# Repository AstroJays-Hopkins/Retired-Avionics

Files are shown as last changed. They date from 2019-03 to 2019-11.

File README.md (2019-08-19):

# Onboard Avionics and Ground Support Electronics

Avionics computer programs (excluding ground station GUI) and circuit schematics.  Program design documents and other non-program files may be found on team internet storage.

## Some directories of interest

* ```propulsion/```  --- Programs that control rocket propulsion systems
  * ```propulsion/darts```  --- Rocket's Data Acquisition, Recording, and Telemetry System
  * ```propulsion/ignition```  --- Programs to monitor and actuate the rocket's ignition hardware
* ```recovery/```  --- Programs that make sure the rocket can fly again
* ```ground-tests/```  --- Programs to help determine if the rocket can (should) even fly in the first place
* ```libraries/```  --- Custom libraries written in-house (one-of-a-kind --- you won't find them elsewhere!) and modified sensor libraries.

For detailed information about a particular subsystem, please consult the READMEs in that subsystem's directory.

_Made in Baltimore with love, tears, caffine, swearing, all-nighters, hair-pulling, stolen code, grimacing, git-cursing, and shocking realizations about engineering._

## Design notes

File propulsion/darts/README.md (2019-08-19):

# Data Acquisition Recording and Transmission System (DARTS)

> <del>_Bata Bacquisition Becording band Bransmission Bystem (BBBbBB)_</del>

Reads data from various sensors
(load cells, pressure transducers, thermocouples),
records the data to disk,
and transmits it to a ground station via WiFi.

## Files

* ```main.py```  --- Main program; calls programs defined in other files
  to collect, record, and transmit data.
  Run this in Python to use the system
  (see section _Starting up the DARTS_).
* ```pressure_transducer.py```  --- Methods to read pressure transducers
  via ADC over I2C
* ```RocketThermocouple.py```  --- Methods to read thermocouples via SPI
* ```load_cell.py```  --- Methods to read load cell via serial.
  Currently only works for single load cell.
  *FIXME:* Implement support for multiple load cells.
* ```HX711_Load_Cell/```  --- Programs that run on actual load cell board (not the Pi).  Consult A. Cornelio for details.
    * ```HX711_Load_Cell/README```  --- A. Cornelio's notes on the load cell program
* ```SendToFlask.py```  --- HTTP client that transmits data
  to Flask server for display on GUI
  (this is how our data gets beamed off the rocket).
  Consult H. Mason for details.
* Files that aren't used or don't work that well:
    * ```3LCtoPi.ino```  --- Serial meta-serializer program for Arduino.
    It's supposed to read three serial inputs (from load cells)
    and collate the data into one long stream
    that it outputs on the fourth serial port to the Pi
    (or other master computer).  Doesn't work, but we're not sure why.
    * ```Server.py``` and ```Client.py```  --- Prototype programs
    to transmit data off of rocket using TCP sockets.
    Kept for historical interest --- the programs have
    some useful instructions on how to determine the IP address of the Pi
    by using a separate computer to log into the system's router.

### Things to be aware of about the code

* GPIO pin numberings in the code use the BCM chip numbering scheme.
  You can find the BCM chip number associated with each header pin
  [here](https://pinout.xyz/).

## Starting up the DARTS

1. Connect the pieces.  See section _Connections_ for details on how to
   connect the sensors, router, and Pi together.
1. Power everything up.
1. Determine the IP address of the Pi.
   Using a separate computer, connect to the system's TP-Link router Wifi signal.
   Then visit tplinklogin.net or 192.168.0.1 in a web browser,
   click on DHCP -> Address Reservation,
   and look for the IP address of the Pi.
   If the Pi's IP address is not immediately obvious,
   compare the MAC addresses listed under DHCP -> Address Reservation
   to that for "blueberrypi" in DHCP -> DHCP Clients List ,
   or eliminate known IP addresses for other computers.
1. Once you have found the IP address of the Pi,
   log into it remotely using SSH:
       ```
          ssh pi@<ip address of Pi>
       ```
   Enter the password to the Pi; you should then see a shell prompt.
1. In the Pi shell over SSH, switch to DARTS code directory:
       ```
          cd rocket/Avionics/propulsion/darts
       ```
1. Start the Python system:
       ```
          python -i main.py
       ```
   System should start reading sensors and transmitting it
   to the Flask server that the GUI obtains data from.
   Data should also be written to file ```DATA1.csv```.
1. On a computer that has the GUI installed,
   start the GUI and navigate to the GUI webpage.
   You should be able to see the GUI displaying data from the sensors.
   For good measure, manipulate the sensors
   and watch for pertubations in their readouts on the GUI.
   For information on how to install and start the GUI,
   please see the GUI's [Git repository](https://github.com/AstroJays-Hopkins/Ground-Station-Wet-Dress).

### SSH

If you're on a Unix-like system,
please refer to your operating system's instructions
for how to install ```ssh```.
Users of Microsoft Windows NT-derived operating systems may download
[PuTTY](https://www.chiark.greenend.org.uk/~sgtatham/putty/).

Note on PuTTY: Ignore the site ```putty DOT org```.
It is not affiliated with the developers of PuTTY
and appears to advertise for competing SSH software.
The correct link to the official PuTTY site is reproduced again here:
[https://www.chiark.greenend.org.uk/~sgtatham/putty/](https://www.chiark.greenend.org.uk/~sgtatham/putty/)

Anyone who is the recipient of unsolicited "sssshhh!" jokes
when discussing SSH is hereby authorized to slap the party
delivering such jokes.
It is further recognised that such "sssshhh!" jokes are stale.

## Connections

__FIXME:__ Document how to put the system together.

## Things to fix, verify, and improve

Until further notice, issues should only be opened on GitHub for problems in code.

- [ ] __VERIFY:__ Is one of the Pis bricked?

- [ ] __VERIFY:__ Does DARTS still calculate critical oxidizer tank conditions and automatically shut off the rocket motor and vent the tank if the tank goes critical?

- [ ] __FIXME:__ Clean up merge conflicts in ```main.py```
- [ ] __FIXME:__ Implement way to read from multiple load cells
- [ ] __FIXME:__ Diagnose thermocouples
- [ ] __FIXME:__ Build better housings and connections between components

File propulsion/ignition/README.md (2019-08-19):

# Ignition system programs and schematics

Name says it all.

Schematic and PCB design are done using [KiCAD](http://kicad-pcb.org/).

## Files

* ```schematic/```  --- Schematics for ignition system
* ```comparator-circuits/```  --- Schematics and PCB design files for the
  continuity tester circuits used in the ignition system

### Things to know about the schematics

* Suggested changes to the schematics are presented in the ```future``` branch.

## Explanation of system

> _Bug avnoks for further details._

The ignition system consists of three parts: the part to light the ematch,
the part to open the oxidizer ball valve,
and the radio device (the "football") that controls the first two parts.
The system is designed around the following principles:

* Safety is implemented in hardware.
  The system's safety should arise from its physical properties,
  not from software checks.
  > Use physical switches as opposed to if statements.
  Never should software be the only thing preventing an unauthorised launch.
* The system should fail safe.
  Should a component of the system stop working,
  it should do so in a way that does not compromise the rest of the system
  and does not cause an unauthorised launch.
* Ultimate control of the system and the launch of the rocket
  should reside in one person.
  This is accomplished by giving the one key
  that arms all switches throughout the system and launches the rocket
  to only one person who is also the last person to leave the pad.
* The system should communicate unambiguously.

### Ematch

The ematch part of the system consists of a battery,
an ematch,
and circuitry to prevent the battery from lighting the ematch
when it's not supposed to.
The battery is housed alongside a relay, radio, and other circuitry
in a relay box located 50 imperial feet away from the rocket
(the radio recieves the command to light the ematch
and activates the relay to connect the battery
to the wires going to the ematch).
The ematch is buried in a block of propellant
suspended in the fuel grain of the rocket;
it is connected to the relay box
through a long wire and some more safety circuitry.
The safety circuitry consists primarily of voltage warning signals,
two switches,
and continuity testers

#### Voltage warning signals

A buzzer and a white LED
in the relay box
and another buzzer and white LED in the rocket
warn launch personnel when there is voltage across the wire
that supplies the ematch with electricity.
Should launch personnel observe these buzzers and LEDs activate,
they should immediately retreat from the pad
and await further instructions.

**FIXME:** Identify frequency of buzzer.

#### Switches

Two key switches are built into the circuit:
a shunt switch,
which is on the relay box,
and a safety switch,
which is on the rocket.
The shunt switch shorts out the wires
that supply electricity to the ematch.
It should be closed whenever personnel are closer to the rocket
than the relay box is (within 50 feet of the rocket).
The safety switch interrupts the wires supplying electricity to the ematch.
It should remain open unless personnel
are about to retreat to a safe area for launch.
Personnel should never close the safety switch
if they observe the voltage warning signals described above.

#### Continuity testers

The continuity testers detect when the switches,
relay,
and ematch in the system have continuity.
For the relay and switches,
the testers sound a buzzer and light an LED
when the component monitored is in an unsafe state
(unsafe means that fewer things need to happen
in order for the rocket to launch).

The continuity testers are built from comparators.
The theory behind them can be found at David Johnson-Davies's
[post on a similar tester.](http://www.technoblogy.com/show?1YON)
In short,
one of the comparator's inputs is tied to a voltage reference
created using a voltage divider.
The other input is connected to one side of the device
whose continuity is to be tested;
the ground of the comparator
is connected to the other side.
When there is continuity,
the second input of the comparator is shorted to ground,
which is less than the reference voltage.
This activates the comparator's output,
which turns on various buzzers and LEDs.

The LM393 comparators used in the system
is an open collector device ---
its output conducts to ground when it is active.

### Motorised Ball Valve (MBV)

Radio module receives launch signal from football.
Waits a bit for relay box to light ematch
and start combustion of fuel grain.
Then checks to see if there still is continuity across the ematch.
If there isn't (match has burnt through),
opens ball valve.

**FIXME:** Where's all the code?

### Football

Radio transceiver that transmits launch command to MBV and relay box.
Should in future receive and display continuity tester data
back from relay box and rocket
(state of relay, switches, and ematch).

## Things to fix

- [ ] **TODO:** Teach everyone on the team what the different signals
                (voltage, continuity)
                look and sound like.
- [ ] **TODO:** Post labels on system describing what to do if a particular signal is observed.

- [ ] __TODO:__ Check design of system in ```future``` branch,
                then order new PCBs.
- [ ] __TODO:__ Assemble modified system

- [ ] __TODO:__ Label physical components with designators from schematics
- [ ] __TODO:__ Build physical housing for system

- [ ] __VERIFY:__ Does MBV controller know when ematch has burnt through?

- [ ] __FIXME:__ Optoisolate inputs between different parts of system
- [ ] __FIXME:__

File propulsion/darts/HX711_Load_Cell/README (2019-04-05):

Andrew's Changes:

Load cell is pretty straightforward now. press a to find the 0 point, b (with a weight on the load cell and correct weight in
kg in the file) to calibrate the load cell, and c to read the weights. Uses some form of gradient descent to find correct
calibration. Don't change unless you know what you're doing. Chances are it's a mechanical failure, not a load cell failure!!!

HX711
=====

An Arduino library to interface the Avia Semiconductor HX711 24-Bit Analog-to-Digital Converter (ADC) for Weight Scales.

This is my humble attempt at creating an Arduino library for this ADC:
http://www.dfrobot.com/image/data/SEN0160/hx711_english.pdf

Other libraries exist, including this very good one, which I first used and which is the starting point for my library:
https://github.com/aguegu/ardulibs/tree/master/hx711

# Advantages of this library
Although other libraries exist, I needed a slightly different approach, so here's how my library is different than others:

1. It provides a tare() function, which "resets" the scale to 0. Many other implementations calculate the tare weight when the ADC is initialized only. I needed a way to be able to set the tare weight at any time. Use case: place an empty container on the scale, call tare() to reset the readings to 0, fill the container and get the weight of the content.

2. It provides a power_down() function, to put the ADC into a low power mode. According to the datasheet, "When PD_SCK pin changes from low to high and stays at high for longer than 60μs, HX711 enters power down mode". Use case: battery powered scales. Accordingly, there is a power_up() function to get the chip out of the low power mode.

3. It has a set_gain(byte gain) function that allows you to set the gain factor and select the channel. According to the datasheet, "Channel A can be programmed with a gain of 128 or 64, corresponding to a full-scale differential input voltage of ±20mV or ±40mV respectively, when a 5V supply is connected to AVDD analog power supply pin. Channel B has a fixed gain of 32.". The same function is used to select the channel A or channel B, by passing 128 or 64 for channel A, or 32 for channel B as the parameter. The default value is 128, which means "channel A with a gain factor of 128", so one can simply call set_gain(). Also, the function is called from the constructor.

4. The constructor has an extra parameter "gain" that allows you to set the gain factor and channel. The constructor calls the "set_gain" function mentioned above.

5. The "get_value" and "get_units" functions can receive an extra parameter "times", and they will return the average of multiple readings instead of a single reading.

# How to Calibrate Your Scale

1. Call set_scale() with no parameter.
2. Call tare() with no parameter.
3. Place a known weight on the scale and call get_units(10).
4. Divide the result in step 3 to your known weight. You should get about the parameter you need to pass to set_scale.
5. Adjust the parameter in step 4 until you get an accurate reading.

# How to use
See the example in examples/HX711SerialBegin. Please don't use examples/HX711Serial anymore. It is deprecated because the pin definition within the constructor
is not timing safe. (#29)

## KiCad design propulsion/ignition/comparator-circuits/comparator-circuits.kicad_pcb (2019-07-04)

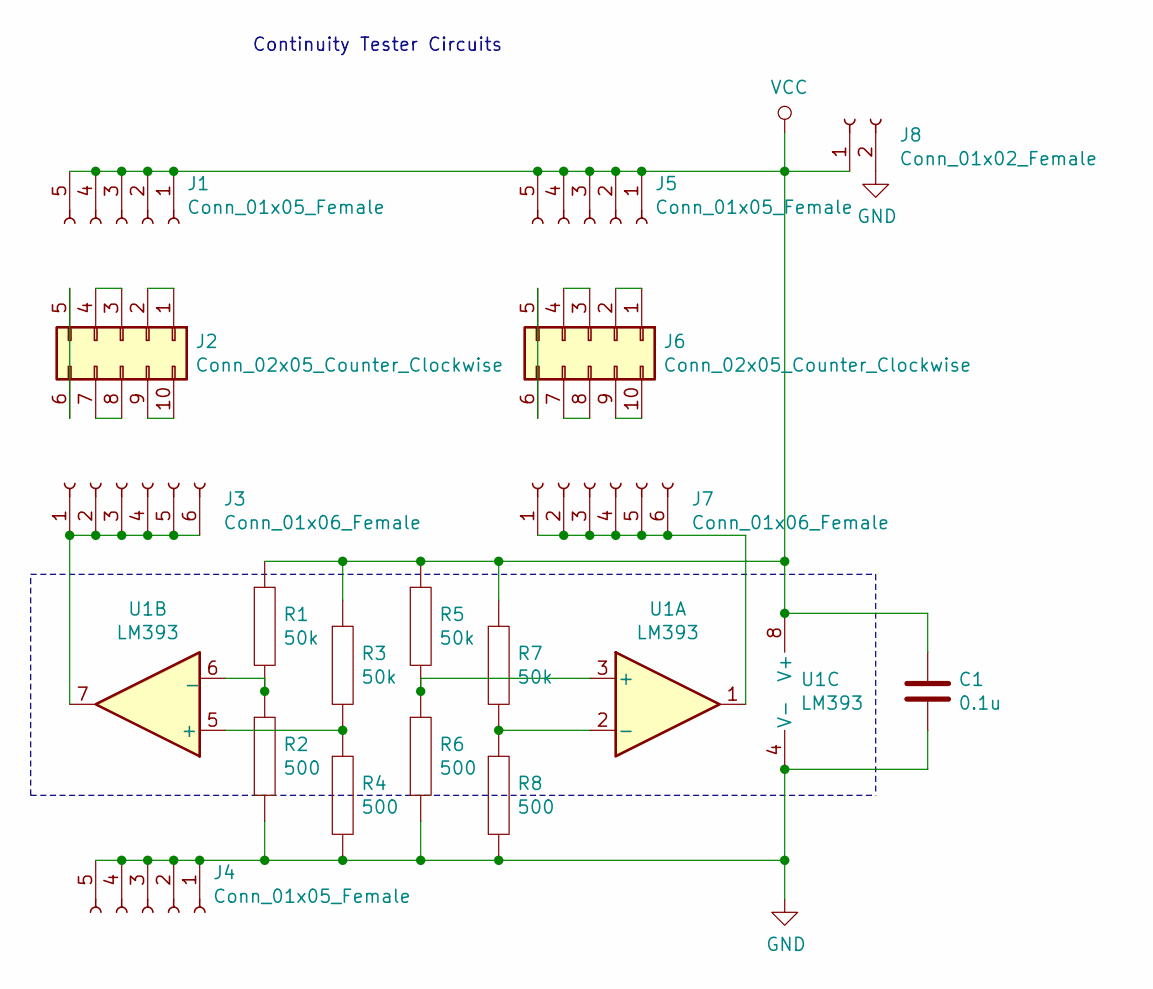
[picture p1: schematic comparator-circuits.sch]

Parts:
C1: 0.1u; C_Disc_D3.0mm_W2.0mm_P2.50mm
J1, J4, J5: Conn_01x05_Female; PinHeader_1x05_P2.54mm_Vertical
J2, J6: Conn_02x05_Counter_Clockwise; PinHeader_2x05_P2.54mm_Vertical
J3, J7: Conn_01x06_Female; PinHeader_1x06_P2.54mm_Vertical
J8: Conn_01x02_Female; PinHeader_1x02_P2.54mm_Vertical
R1, R3, R5, R7: 50k; R_Axial_DIN0207_L6.3mm_D2.5mm_P7.62mm_Horizontal
R2, R4, R6, R8: 500; R_Axial_DIN0207_L6.3mm_D2.5mm_P7.62mm_Horizontal
U1: LM393; DIP-8_W7.62mm

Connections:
GND: C1.2, J4.1, J4.2, J4.3, J4.4, J4.5, J8.2, R2.2, R4.2, R6.2, R8.2, U1.4 (V-)
unnamed: J2.1, J2.2
unnamed: J2.3, J2.4
unnamed: J2.5, J2.6
unnamed: J2.7, J2.8
unnamed: J2.9, J2.10
unnamed: J3.1, J3.2, J3.3, J3.4, J3.5, J3.6, U1.7
unnamed: J6.1, J6.2
unnamed: J6.3, J6.4
unnamed: J6.5, J6.6
unnamed: J6.7, J6.8
unnamed: J6.9, J6.10
unnamed: J7.1, J7.2, J7.3, J7.4, J7.5, J7.6, U1.1
unnamed: R1.2, R2.1, U1.6 (_)
unnamed: R3.2, R4.1, U1.5 (+)
unnamed: R5.2, R6.1, U1.3 (+)
unnamed: R7.2, R8.1, U1.2 (-)
VCC: C1.1, J1.1, J1.2, J1.3, J1.4, J1.5, J5.1, J5.2, J5.3, J5.4, J5.5, J8.1, R1.1, R3.1, R5.1, R7.1, U1.8 (V+)

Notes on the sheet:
Continuity Tester Circuits

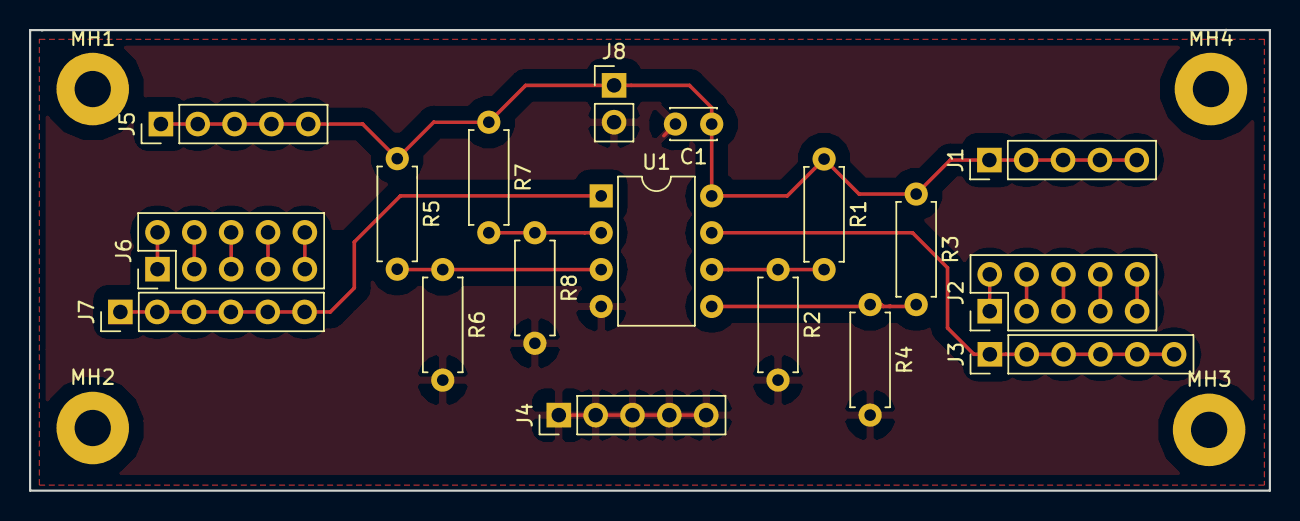
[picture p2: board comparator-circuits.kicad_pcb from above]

Board: 2 copper layers, 85.5 x 31.8 mm, 22 parts (0 on the bottom side), 18 nets.

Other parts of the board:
MH1, MH2, MH3, MH4: MountingHole_2.5mm_Pad

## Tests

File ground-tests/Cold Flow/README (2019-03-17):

Peripheral_Mega.ino 
----------------------------------------------------------
>collects data from load cells using UART serial communication 
>calculates venting time based off duration of continutity of a button press circuit
>determines open/closed condition of quick disconnect solenoid
>writes data to ground station via I2C communication

Sensing_Mega.ino
----------------------------------------------------------
>collects pressure data via analog pressure transducers
>collects temperature data using SPI thermocouples
>determines critical condition of the oxidizer
>sends back information via I2C communication

Ground_Station_Reader.ino
----------------------------------------------------------
>collects information sent from peripheral and sensing devices
>formats data for use in Flask.app GUI
>exports data for use in GUI via UART serial communication
>logs data on SD card

Wet_Dress.ino
----------------------------------------------------------
>serves the same purpose as Peripheral_Mega.ino and Sensing_Mega.ino but on one board
>transmits data via USB serial to GUI

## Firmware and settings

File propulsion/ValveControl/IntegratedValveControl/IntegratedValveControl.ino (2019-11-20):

/* 
 *  Control code for ball valve and solenoid valves.  
 *  Reads Hall effect detector
 *  built into the AndyMark RS-775 motor to measure rotation.
 *  
 *  The ball valve section of the code is:
 *  Code adapted and pilfered from Jeffrey La Favre:
 *    http://www.lafavre.us/robotics/encoder_code.pdf
 *  An explanation of Hall effect encoders, also 
 *  by La Favre: 
 *    http://www.lafavre.us/robotics/Hall_Encoders.pdf
 *  Do take the technical explanation located above with a grain of salt.
 *  
 *  BEFORE EDITING THIS PROGRAM, please read the
 *  "Notes and Warnings" on interrupts here: 
 *    https://www.arduino.cc/reference/en/language/functions/external-interrupts/attachinterrupt/
 *
 */

//Commands will be sent via 915MHz radio communication
#include <SPI.h>
#include <LoRa.h>
#include <Wire.h>
#include <TimerOne.h>

#include "motor.h"
#include "radio.h"

/* *** MOTOR RELAY PINS for BV VALVES*** */
// Signal pin to relay that is currently powering motor.  If no relay is
// currently on (running a motor), this variable will be 0 .
int Active_Relay_Pin = 0;
int Low_Relay_Pin = 0;
const int PIN_EMATCH_CONT = 52;


// States for the above pins
bool Valve_state = false;   // HIGH -> open; LOW -> closed 


/* *** RELAY PINS for Solenoid Valves */
const int fuelRelay = 6;
const int ventRelay = 23;
//States for the above pins
bool Fuel_state = false;
bool Vent_state = false;

/* *** IGNITION PARAMETER *** */
volatile uint8_t igniter_x_cnt = 0;
volatile uint8_t stop_x_cnt = 0;
volatile bool ignited = false;
bool shut_bv_after_ignition = false;
const int burn_duration = 650; // The duration for the ignition burn, in 10ms.
long burn_time = 0;

bool ematch_continuity = false; // Check if ematch is burnt through.

DCMotorController MV_R1(rkt::MV_R1_CLICKS);

void MV_R1_pulse() {
  MV_R1.handlePulseEvent();
}

void MV_R1_limit() {
  MV_R1.handleLimitSwitch();
}


void switch_solenoid_valve(int valve_pin, int state){
  digitalWrite(valve_pin, state);
}

void stopRun() {
  // The ignition function will run twice before we actually want it to ignite
  // Once when the interrupt is attached, and once when the timer is started
  if (stop_x_cnt > 1) {
    MV_R1.actuate(1);
    Timer1.stop();
    Timer1.detachInterrupt();
    stop_x_cnt = 1;
  } else {
    ++igniter_x_cnt;
  }
}

void ignition() {
  // The ignition function will run twice before we actually want it to ignite
  // Once when the interrupt is attached, and once when the timer is started
  if (igniter_x_cnt > 1) {
    MV_R1.actuate(2);
    Timer1.stop();
    Timer1.detachInterrupt();
    Timer1.setPeriod(7000000);
    Timer1.stop();
    Timer1.attachInterrupt(stopRun);
    Timer1.start();
    igniter_x_cnt = 1;
  } else {
    ++igniter_x_cnt;
  }
}

void emergency() {
    // fill with emergency code
}

//Every time data is requested, send data back.
void writeI2C() {
  uint8_t ecstate = (int) Vent_state; //vent
  ecstate += (int) MV_R1.valve_moving << 1; //ball valve Moving
  ecstate += (int) MV_R1.state << 2; //ball valve
  ecstate += (int) ematch_continuity << 3; //e-match
  ecstate += (int) Fuel_state << 4; //fuel
  Wire.write(ecstate);
}

void readI2C() {
  byte command = Wire.read();
  // read off vent command
  commands[2] = (command & (0b11 << 1)) >> 1;
  // emergency shutdown command
  if(command & 0b1) emergency();
}

RfTr rf_tr(0b0001);

void setup() {
  /* Initialize radio communication protocol */
  LoRa.begin(915E6);
  LoRa.setTxPower(2);
  Serial.begin(115200);
  Wire.begin(0x10);
  Wire.onReceive(readI2C);
  Wire.onRequest(writeI2C);

  /* Initialize relay signal pins */
  pinMode(rkt::PIN_MOTOR_FWD, OUTPUT);
  pinMode(rkt::PIN_MOTOR_REV, OUTPUT);
  
  //set relay pins to output voltage
  pinMode(ventRelay,OUTPUT);
  pinMode(fuelRelay, OUTPUT);
  pinMode(rkt::PIN_INTR_ENCODER, INPUT);
  pinMode(rkt::PIN_INTR_LIMIT, INPUT_PULLUP);

  attachInterrupt(digitalPinToInterrupt(rkt::PIN_INTR_ENCODER), MV_R1_pulse, RISING);
  attachInterrupt(digitalPinToInterrupt(rkt::PIN_INTR_LIMIT), MV_R1_limit, FALLING);

  //set default relay states to LOW (default)
  digitalWrite(ventRelay, HIGH);
  digitalWrite(fuelRelay, LOW);
  digitalWrite(rkt::PIN_MOTOR_FWD, LOW);
  digitalWrite(rkt::PIN_MOTOR_REV, LOW);

//  //setup timer2 interrupt for ignition procedure. 1kHz -> 64 prescalar + 249 compare interrupt
//  // The control of the rocket will be disabled during ignition if delay() is used, which is blocking.
//  TCCR2A = 0;
//  TCCR2B = 0;
//  TCNT2 = 0;
//  OCR2A = 249;
//  
//  TCCR2A |= (1 << WGM21);
//  TCCR2B |= (1 << CS22);
//  TIMSK2 |= (1 << OCIE2A);
  Serial.print("Set Pulses: ");
  Serial.println(MV_R1.set_pulses);
  sei();
  Timer1.initialize(650000);
  Timer1.attachInterrupt(ignition);
  Timer1.stop();
}

//void ignition_duration_check(){
//  if (ignited && (ematch_continuity = true) ){
//    burn_time += 1;
//    if (burn_time >= burn_duration){
//      RECVD_IG_CMD = 0;
//      MV_R1.actuate(2);
//      shut_bv_after_ignition = true;
//    }
//  }
//}

void checkEMatchCont() {
  ematch_continuity = digitalRead(PIN_EMATCH_CONT);
}

int curPulse = 0;

void loop() {
//  if(curPulse != MV_R1.current_pulses) {
//    curPulse = MV_R1.current_pulses;
//    Serial.print("PULSE CHANGED: ");
//    Serial.println(curPulse);
//  }
  // Put code in to activate relays upon request.
  rf_tr.check_receive_packet();
  checkEMatchCont();
    
  uint8_t BV_Command = commands[0]; //check ball valve desired state
  switch (BV_Command) { //set desired ball valve state
    case 255: // TODO check char types
      Serial.println("IG CASE");
      Serial.println("RECVD IGNITION CMD...");
      Timer1.restart();
      commands[0] = 2;
      break;
  case 2:
    Serial.println("Valve Open");
    MV_R1.actuate(2);
    commands[2] = 0;
    break;
  case 1:
    Serial.println("valve close");
    MV_R1.actuate(1);
    commands[2] = 0;
    break;
  case 0:
    // Serial.println("HOLDING");
    break;
  }

  int8_t Fuel_Command = commands[2]; //Check fuel valve desired state
  switch (Fuel_Command) { //set desired fuel valve state
    case 2:
      Fuel_state = true;
      Serial.println("FUEL OPEN");
      break;
    case 1:
      Fuel_state = false;
      Serial.println("FUEL CLOSE");
      break;
  }
  
  int8_t Vent_Command = commands[1]; //Check vent valve desired state
  switch (Vent_Command) { //set desired vent valve state
    case 2:
      Vent_state = true;
      switch_solenoid_valve(ventRelay, 1); //Vent valve is normally open.
      commands[0] = 2;
      break;
    case 1:
      Vent_state = false;
      switch_solenoid_valve(ventRelay, 0);
      commands[0] = 1;
      break;
  }
  commands[0] = 0;
  commands[1] = 0;
  commands[2] = 0;
  //Serial.println("------------------------------");
}

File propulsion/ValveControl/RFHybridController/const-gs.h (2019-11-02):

#ifndef __CONST_GS_H__
#define __CONST_GS_H__

namespace rkt {
    const uint8_t PIN_IN_SV_R1_ENA   = 49;
    const uint8_t PIN_IN_MV_G1_CLOSE = 48;
    const uint8_t PIN_IN_IGNITION    = 47;
    const uint8_t PIN_IN_MV_G1_OPEN  = 46;
    const uint8_t PIN_IN_MV_R1_CLOSE = 45;
    const uint8_t PIN_IN_MV_R1_OPEN  = 43;
    const uint8_t PIN_IN_VENT        = 41;

    const uint8_t LED_SYS_ERR     = 39;
    const uint8_t LED_RKT_ACK_ERR = 37;
    const uint8_t LED_IGC_ACK_ERR = 35;
    const uint8_t LED_COM         = 33;
    const uint8_t LED_LINK        = 31;
}
#endif

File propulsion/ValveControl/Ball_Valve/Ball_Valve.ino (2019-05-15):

/* 
 *  Ball valve control code.  Reads Hall effect detector
 *  built into the AndyMark RS-775 motor to measure rotation.
 *  
 *  Code adapted and pilfered from Jeffrey La Favre:
 *    http://www.lafavre.us/robotics/encoder_code.pdf
 *  An explanation of Hall effect encoders, also 
 *  by La Favre: 
 *    http://www.lafavre.us/robotics/Hall_Encoders.pdf
 *  Do take the technical explanation located above with a grain of salt.
 *  
 *  BEFORE EDITING THIS PROGRAM, please read the
 *  "Notes and Warnings" on interrupts here: 
 *    https://www.arduino.cc/reference/en/language/functions/external-interrupts/attachinterrupt/
 *
 */

/*
 * Connections: 
 *   Ch. A --> Digital 2
 *   Ch. B --> Digital 3
 */

//Commands will be sent via 915MHz radio communication
#include <SPI.h>
#include <LoRa.h>

/* *** MOTOR RELAY PINS, CONTROL FUNCTIONS *** */

// Signal pin to relay that is currently powering motor.  If no relay is
// currently on (running a motor), this variable will be 0 .
int Active_Relay_Pin = 0;
// Signal pins to relays.
// Program assumes that one relay spins the motor forwad and the other relay
// is connected to the motor backwards to spin it in reverse.
const int MOTOR_FORWARD_RELAY_PIN = 5;
const int MOTOR_REVERSE_RELAY_PIN = 6;
// Forward opens; reverse closes
// Signal pins to Pi
const int VALVE_MOVING_INDICATOR_PIN = 7;
const int VALVE_STATE_INDICATOR_PIN = 8;
const int ematch_pin = 9;
// States for the above pins
bool Valve_moving = LOW;  // If HIGH -> valve is moving; LOW -> not moving
bool Valve_state = LOW;   // HIGH -> open; LOW -> closed 

bool RECVD_IG_CMD = 0;

void turn_motor_off () {
  digitalWrite(Active_Relay_Pin, LOW);
  Valve_moving = LOW;
  digitalWrite(VALVE_MOVING_INDICATOR_PIN, LOW);
  Active_Relay_Pin = 0;
}

void turn_motor_on_forward () {
  // If the motor is on, turn it off first.
  if (!Active_Relay_Pin) {
    turn_motor_off();
  }
  digitalWrite(MOTOR_FORWARD_RELAY_PIN, HIGH);
  Active_Relay_Pin = MOTOR_FORWARD_RELAY_PIN;
  // Set valve moving state and pin
  Valve_moving = HIGH;
  digitalWrite(VALVE_MOVING_INDICATOR_PIN, HIGH);
}  

void turn_motor_on_reverse () {
  // If the motor is on, turn it off first.
  if (!Active_Relay_Pin) {
    turn_motor_off();
  }
  digitalWrite(MOTOR_REVERSE_RELAY_PIN, HIGH);
  Active_Relay_Pin = MOTOR_REVERSE_RELAY_PIN;
  // Set valve state and pin
  Valve_moving = HIGH;
  digitalWrite(VALVE_MOVING_INDICATOR_PIN, HIGH);
}

/* *** MOTOR HALL EFFECT ENCODER *** */

int Encoder_Pulse_Count[2] = {0, 0};
                // Channels: {A, B}

void reset_pulse_count () { 
  Encoder_Pulse_Count[0] = 0;
  Encoder_Pulse_Count[1] = 0;
}

// Increment pulse count for channel A
void increment_channel_a () { 
  Encoder_Pulse_Count[0] += 1;
  check_rotation_and_stop_if_needed();
}

// Increment pulse count for channel B
void increment_channel_b () { 
  Encoder_Pulse_Count[1] += 1;
  check_rotation_and_stop_if_needed();
}

bool ematch_continuity() { 
  return !digitalRead(ematch_pin); 
}

/*
 * Gearbox between motor and ball valve has a 188:1 reduction ratio.  
 * To turn the ball valve \pi/2 radians, the motor has to spin 47 times.
 * The encoder produces 7 pulses per revolution.  
 * To spin the ball valve \pi/2 radians, we will need to count 329 pulses.
 */
void check_rotation_and_stop_if_needed () {
  /* Checks to see if motor has spun 90 degrees */
  if ((Encoder_Pulse_Count[0] >= 329) || (Encoder_Pulse_Count[1] >= 329)) {
    /* Shut off motor if that's the case. */
    turn_motor_off();
    reset_pulse_count();
    if (Active_Relay_Pin == MOTOR_REVERSE_RELAY_PIN) { 
      
    }
  }
}

void setup() {
  /* Initialize radio communication protocol */
  LoRa.begin(915E6);
  
  /* Initialize Hall effect pulse counter interrupts */
  attachInterrupt(digitalPinToInterrupt(2), increment_channel_a, RISING);
  attachInterrupt(digitalPinToInterrupt(3), increment_channel_b, RISING);
  
  /* Initialize relay signal pins */
  pinMode(MOTOR_FORWARD_RELAY_PIN, OUTPUT);
  pinMode(MOTOR_REVERSE_RELAY_PIN, OUTPUT);
  pinMode(ematch_pin, INPUT);
  
  // For testing:
  Serial.begin(9600);
}

void loop() {
  // Put code in to activate relays upon request.
  String command;
  int packetSize = LoRa.parsePacket();
  if (packetSize) {
    while (LoRa.available()) { //get full RF command
      command += LoRa.read();
    }
    Serial.println(command);
  }
  
  if (RECVD_IG_CMD == 1 && !ematch_continuity()) { 
    // digitalWrite(IGPIN,HIGH);
    delay(2650);
    turn_motor_on_forward();
    delay(6500); //delay for however long we want the motor to burn for, 6.5 seconds being the most recent specified time
    turn_motor_on_reverse();
  }
  char BVCommand = command[2]; //check ball valve desired state
  switch (BVCommand) { //set desired ball valve state
  case 'F': 
    Serial.println("FORWARD");
    turn_motor_on_forward();
    break;
  case 'R':
    Serial.println("REVERSE");
    turn_motor_on_reverse();
    break;
  case 'I': 
    Serial.println("RECVD IGNITION CMD...");
    RECVD_IG_CMD = 1;
    break;
  case 'X':
    Serial.println("HOLDING");
    break;
  }
}

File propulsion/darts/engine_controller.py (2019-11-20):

# Moved from `main.py` Check that file for version control history.
# import general purpose input/output
try:
    # RPi.GPIO documentation: https://sourceforge.net/p/raspberry-gpio-python/wiki/
    import RPi.GPIO as GPIO
except ImportError:
    print("Error importing RPi.GPIO! This is probably because you need"
          "superuser privileges.  You can achieve this by using 'sudo'"
          "to run your script")
from adafruit_bus_device.i2c_device import I2CDevice

from constants import Const

class EngineController:
    '''
    Class to interface with the ignition computer. currently an Arduino Mega,
    but subject to change. This is where we cross into the firm-time bound, so
    all communications methods chosen should be time-definite.

    NOTE: This "coprocessor" is also known as the "Engine Controller"
    '''
    ## FIXME MAYBE  Should we have a function to order the arduino to open the ball valve?


    # Tell ignition computer to close motorized ball valve.
    # Doesn't actually close the valve (that's the igcomp's job) --- hence the name
    def __init__(self, i2c):
        '''
        Initialize mechanisms used by the ignition computer to interface with
        the flight computer.

        Right now, the coprocessors communicate over I2C due to the short rnage
        involved
        '''
        try:
            self._sc_device = I2CDevice(i2c, Const.I2C_ADDR_SC)
        except ValueError:
            print("[ECI] Error initializing SC device")
        try:
            self._ec_device = I2CDevice(i2c, Const.I2C_ADDR_EC)
        except ValueError:
            print("[ECI] Error initializing EC device")
        self._buf = bytearray(1)
        self.updateFailed = False
        self.SCVState = False
        self.ecCommand = 0b0
        self.firstrun = False
        self.state = {'MV_S1': None,
                      'MV_R1': None,
                      'MV_R1_moving': None,
                      'MV_G1': None,
                      'eMatch': None}
        self.update()
        self.SCVState = self.state['MV_G1']

    def _writeI2C(self, device):
        '''
        Write the instance buffer _buf to the I2C device at `device`

        :param device: I2C device to write out to
        '''
        try:
            with device as dev:
                dev.write(self._buf)
        except Exception as e:
            print(str(e))
            print("[ECI] Error writing to device at address"
                  "{}".format(device.device_address))

    def emergency_shutdown(self):
        '''
        Carry out procedures needed to make the engine shut down
        '''
        # Vent() # Ask DAAAAAAAN
        self._buf[0] = 0b1
        self._writeI2C(self._ec_device)

    def setVent(self, state):
        """
        Tell ignition computer to open venting solenoid

        :param state: True to open the vent velve, False to close
        """
        if state == true:
            self.ecCommand |= 0b10 << 1
        if state == false:
            self.ecCommand &= ~(0b11 << 1)
            self.ecCommand |= 0b01 << 1 
        self._buf[0] = self.ecCommand
        self._writeI2C(self._ec_device)
        self.ecCommand &= ~(0b11 << 1)

    def update(self):
        '''
        Requests current engine and engine actuator states from the engine
        controller and buffers it in the state variable.

        This function should be called in every cycle before the "get" functions
        are called.
        '''
        self._buf[0] = 0
        try:
            with self._ec_device as dev:
                dev.readinto(self._buf)
        except Exception as e:
            print(str(e))
            print("Error with updating engine data")
            self.updateFailed = True
        print(bin(self._buf[0]))

        self.state['MV_G1']        = bool((self._buf[0] >> 4) & 0b1)
        self.state['eMatch']       = bool((self._buf[0] >> 3) & 0b1)
        self.state['MV_R1']        = bool((self._buf[0] >> 2) & 0b1)
        self.state['MV_R1_moving'] = bool((self._buf[0] >> 1) & 0b1)
        self.state['MV_S1']        = bool(self._buf[0] & 0b1)

        if(not self.firstrun and self.state['MV_G1'] != self.SCVState):
            self._buf[0] = int(self.state['MV_G1'] + 1)
            print("moving G1: {}".format(str(self._buf[0])))
            self._writeI2C(self._sc_device)
            self.SCVState = self.state['MV_G1']

    def getFuelSolState(self):
        '''
        Get the last state of the fueling valve. Like all valves, true is open
        and false is closed.
        '''
        if(self.updateFailed):
            return "E[FSS]"
        return self.state['MV_G1']

    def getVentState(self):
        '''
        Get the last state if the venting solenoid. Like all valves, true is
        open and false is closed
        '''
        if(self.updateFailed):
            return "E[VS]"
        return self.state['MV_S1']

    def getBallValveState(self):
        '''
        Get the last state of the rocket valve MV-R1. Like all valves, true is
        open and false is closed.
        '''
        if(self.updateFailed):
            return "E[BVS]"
        return self.state['MV_R1']

    def getEmatchState(self):
        if(self.updateFailed):
            return "E[EMS]"
        return self.state['eMatch']

    def getBallValveMovingState(self):
        """ Checks pin from Arduino indicating if the ball valve is being actuated.
        """
        if(self.updateFailed):
            return "E[BVMS]"
        return self.state['MV_R1_moving']

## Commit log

2018-11-11 Disable timer-based deployment; fix relay HIGH/LOW
    Commented out timer-based deployment switch statement; edited relay-related digitalWrite() calls to use LOW when relays are supposed to close and to use HIGH when relays are supposed to (remain) open.
    [MEGA.ino]
2018-11-30 Add files via upload
    Program to control hybrid motor sensors and actuators
2018-11-30 Update Hybrid.ino
    Created an array of thermocouples to take temperature values at two points on the run tank and combustion chamber
2018-11-30 Misc. bugfixes; changed some #include statements; added MUSIC_STOP command.
    [MEGA.ino]
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2018-12-04 Update Hybrid.ino
    Updated thermocouple sensor/data array structures, redefined value for ignition command, nested ignition command in conditional statement that tests for arming condition so ignition cannot occur duri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
2018-12-23 Added range test code. Fixed indentation of bracket in Hybrid.ino .
    [Hybrid.ino, range-test.ino]
2019-01-09 Added error checking when calling radio.write() .
    [range-test.ino]
2019-01-11 Radio identity now determined by shorting out input pin. Added function calls to print debug information; increased number and length of delays.
    [range-test.ino]
2019-01-11 Added printf.h to dump radio details; abstracted printing debugging information to function; indicated radio identity when printing debugging information.
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2019-01-13 pins / music
    Fixed HIGH output in staging for drogue / main pins, added additional music files
    [MEGA.ino]
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2019-01-31 Record-keeping ... updated range test code that we won't use.
    [range-test.ino]
2019-02-02 First Contact
    -changed radio communication libraries
    -restructured RF communication to only send flight data to ground station
2019-02-02 Corrected pinouts
    SEP and R are set HIGH, then turn LOW. SEP = 3, R = 5 (flipped location of drogue and main)
    [MEGA.ino]
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2019-03-01 Update GROUND_STATION.ino
    added new LoRa library, parses single packet for info rather than logging individual values sent, adds datalogging capability
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2019-03-02 Changed one relay signal pin and added a smidgen of documentation for the relay connections.
2019-03-02 Fixed relay pin constant in turn_motor_on_reverse(); edited comment.
    [ball-valve-control.ino]
2019-03-03 Add files via upload
    Peripheral_Mega.ino - data from load cells and solenoid buttons, sends via I2C to Ground_Station_Reader.ino
    Sensing_Mega.ino - data from thermocouples and pressure transducers, critical condition, sends via I2C to Ground_Station_Reader.ino
    Ground_Station_Reader.ino - collects and formats data from sensing/peripheral devices for output into GUI and storage on an SD card
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2019-03-07 Fixed bugs related to misnamed functions, Encoder_Pulse_Count , and missing call for reset_pulse_count() .
    [ball-valve-control.ino]
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2019-03-18 Revert "folder change"
    This reverts commit 8c865882d8dbeeaf4b2815698954fac62de97615.
    [load_cell.py, main.py]
2019-03-18 More directory reorganization. Created "ground-tests", "recovery" directories. Moved several relevant files and directories to new directories.
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2019-03-24 Moved "Client.py", "RocketThermocouple.py", "Server.py", and "socket.py" to "propulsion/". Modified MUX select functions for load cells and load-cell read-iteration; added torpedo's logging routines 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
2019-03-31 replaced get_state functions; defined state variables
    [main.py]
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2019-04-02 implemented RF capability
    Commands are no longer sent via UART serial to the Arduino, but rather via 915 MHz from another Arduino running the Ball_Valve_Ground_Station code.
    [ball-valve-control.ino]
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2019-04-04 Some quick changes that I no longer remember...
    [RocketThermocouple.py, main.py]
2019-04-05 Bugfixes and feature additions galore. Now communicates over WiFi. Lots of other things done.
    [RocketThermocouple.py, Server.py, load_cell.py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]
2019-04-05 Added code to transmit and detect states of ball valve; shuffled around load cell files.
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2019-04-27 Changed index of command string used to for ignition character in Ball_Valve.ino; added program for relay box.
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2019-05-15 added safety counter variable to prevent repeat ignition
    [Ball_Valve.ino]
2019-05-15 Fixed bug that read char as ASCII values
    [RFValves.ino]
2019-07-04 Added schematics for ignition system and PCB design files for continuity testers. Files represent system as physically constructed as of 4 July 2019.
    [comparator-circuits.kicad_pcb, comparator-circuits.sch, relay-box-continuity-tester.sch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]
2019-10-04 Create IntegratedValveControl.ino
    The code for controlling all the valves with 1 Arduino mega.
2019-10-06 darts: Misc changes
    Modified TC callibration and general error messages in data
    collection failures.
    [RocketThermocouple.py, main.py, pressure_transducer.py]
2019-10-06 darts: LC_Reader convert to new format
    Convert loadcells class to read loadcells using the new openscale firmware.
    The new firmware has been configured to output a string in the format
    `[timestamp],[value],[units],` every 100ms. Since our current loop
    interval is configured to cycle every 0.01s, we return the last buffered
    read until the loadcell has new data available. Read logic has been
    moved from a free standing function to a class to enhance code
    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
2019-10-06 load_cell.py: Reduce timeout
    Reduced default loadcell serial read timeout to 0.1 second to prevent major
    loop delays when a serial read times out.
    [load_cell.py]
2019-10-06 load_cell.py Docstring improvements
    Fixed typoes and added docstrings for the two loadcell classes.
    [load_cell.py]
2019-10-06 load_cells.py: Fix disconnected loadcell state
    Incorrect exception handler, it should set the loadcell list to none to
    allow the logic test. This is kludge and should be removed when it's
    time to go to prod.
    [load_cell.py]
2019-10-12 Update IntegratedValveControl.ino
    This is the working version of the valve control code for onboard Arduino.
2019-10-12 darts/load_cell.py: Fix typo
    Small typo causing syntax errors is now fixed. CI could have prevented
    this from being committed.
    [load_cell.py]
2019-10-12 darts/load_cell.py: Tweak read params
    Read, then dump buffers when data is available to prevent waiting for
    new data and blocking the entire read loop.
    [load_cell.py]
2019-10-13 darts/main.py: Add fixme
    Critical pressure is incorrect almost certainly. should be fixed before
    hotfire.
    [main.py]
2019-10-13 Add relay_box_pintest.ino
    This is the Arduino code used as transmitter for testing of the valve control of inboard Arduino, imitates the behaviour of football.
2019-10-13 RFHybridController.ino: Bug fix
    Command only sent by transmitter when there is a new command
    [RFHybridController.ino]
2019-10-15 Update IntegratedValveControl.ino
    Replaced the interrupt with a timer control, whilst making the code slightly more compact.
    [IntegratedValveControl.ino]
2019-10-24 darts/RocketThermocouple: Adapt to new paradigm
    Move reading functions into a reading lcass to package data with
    associated methods. This should also solve the "erroring thermocouples
    always come last, no matter what port they're plugged into bug" by
    reserving a list of TC object in the reader class.
    [RocketThermocouple.py, main.py]
2019-10-24 darts/pressure_transducer: Use Reader Class
    Converted the scattered reading functions to a reader class to allow
    easier PressureTransducer object manipulation.
2019-10-24 darts/main: Convert data aquisition to json
    Converted data telemetry output to json to enable more robust telemetry
    dashboards. This allows the dashboard to automatically parse and extract
    the right sensors to display, even if the underlying sensor arrays
    change.
2019-10-26 ValveControl: Modify to use new controls
    The file has been modified to use the new control surface fabricated for
    the horfire. See schematics for what changed, including pin
    reassignments, and other new features.
2019-10-26 RFHybridController: Redo Buttons
    Fixes reliability issue with button by "debouncing" inputs for 50ms
    before allowing accepting the input. This prevents button activation
    occilations from effecting the output and causing multiple commands to be
    sent.
    Buttons have been modularized into a struct. While this is cpp, care has
    been taken to minimize performance and cruft overhead of running cpp on
    a MCU by doing absolutely no dynamic memory management. This means that
    our classes structs must have all classes know what variables they need
    when they are compiled.
    [RFHybridController.ino, util.h]
2019-10-26 RFHybridController: Formatting Fixes
    Standardized indent to four spaces, one space between if condition and
    opening brace, and linewrap at 80 chars.
    [RFHybridController.ino]
2019-10-26 ValveControl: Modify to work with MV_R1
    Patched button handler to properly interact with new control surfaces
    and tweaked engine controller code to actuate the primary rocket valve
    correctly.
    [RFHybridController.ino]
2019-10-26 RFHybridController: Update to latest Spec
    Updated ground station frimware to be compliant with v0.4.0 of the
    Propulsion Avionics Control Plane Spec. This includes new acking
    protocols, a more logical command scheme (0 is now always a noop),
    formalization of packet headers/metadata, and a sequence code based
    command synchonization. NACKs are pending in a future revision of the
    specs.
2019-10-26 ValveControl: Fix control scheme
    Fixed the acks to properly correspond with sequence.
    [IntegratedValveControl.ino, RFHybridController.ino, constants.h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]
2019-10-28 ValveControl: Split out common constants
    Split constants header to shared constant and device specific constant headers
    to enhance reusability and readability.
2019-10-28 VavleControl: Fix Radio heartbeats
    Hearts beats were not being processed correctly. They should work
    properly now.
    [IntegratedValveControl.ino, util.h]
2019-10-28 RelayBox: Adapt to new protocol
    Adapted Relay control box to new acknowledgement based protocol with
    outmatic timeout/shutdown capabilities. Currently the relaybox will
    silently shutdown after 30 seconds of missed awknowledgements and will
    need to be reset to start recieivng again.
    [const-common.h, relayBox.ino]
2019-10-28 StepperController: Add initial implementation
    Implemented the stepper controller to control the ground-side fueling
    valve. Currently, it relies on the I2C bus master to update its status
    as necessary.
2019-10-28 darts: Fix CSV Output
    CSV actually outputs in the correct order now with correct values.
    Unfortunately, as a temporary kludge, this order is hardcoded. This
    should be fixed later.
    [main.py]
2019-10-28 darts: Implement I2C Engine Interface
    Using I2C simplifies wiring and enhances reliability, while allowing more
    data to be sent as necessary. Overall, this is a much more robust system
    that should fail less and more predictably
    [constants.py, engine_controller.py, main.py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]
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2019-10-28 IntegratedValveControl: Fix I2C functionality
    Fixed incomplete implementation of the I2C protocol specced out and
    changed variable states to sane defaults to ensure initial data
    collected is always correct. This is the second part of the I2C
    implementation project.
    [IntegratedValveControl.ino]
2019-10-31 RFHybridControler: Move pins to const
    Moved pin names to constant file, and fixed pins to not conflict with
    radio communications. Also fixed small logic errors preventing the
    controller from working properly.
    [RFHybridController.ino, const-common.h, const-gs.h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]
2019-10-31 IntegratedValveControl: Fix command codes
    Fixed command codes so that BVOPEN and BVCLOSE commands actually actuate
    the valves in the right direction.
    [IntegratedValveControl.ino]
2019-10-31 StepperController: Fix Turn logic
    Missing breaks in switch statement cuased open comands to carry on to
    close commands, thereby actuating a net 0 rotation. this is now fixed
    and the actuation should proceeded as expected. Also, lockouts have been
    added to prevent the valve from actuating in the same direction twice.
    [StepperController.ino]
2019-10-31 darts/engine_controller.py: Fix _SC object
    The Stepper controller obeject was being called icnorrectly causing an
    instant error when attempting to write to it. It has been fixed now.
    [engine_controller.py]
2019-10-31 RFHybridController: Add Solenoid Lockout
    Lockout solenoid in closed (flow open) position until the rocker switch
    is flipped to the on position, which will then allows the button to be
    used to manually trigger vent.
    [RFHybridController.ino, const-gs.h]
2019-11-02 ValveControl: Fix ignition pins
    Modified relaybox code to use proper pins for ignition and GS code to
    send the right command to the right places.
    [RFHybridController.ino, relayBox.ino]
2019-11-02 StepperController: Disable movement on first read
    Prevented the stepper controller from moving at the first read and
    synced the flight computer state to prevent movement in the wrong
    direction if the valve is not in the initial position expected.
    [StepperController.ino, const-gs.h, engine_controller.py]
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2019-11-06 Valve Control: Fix valve state conventions
    OPEN means that the valve allows flow and CLOSED means that the valve
    does not allow flow. Remember this you doofus! In other words, the vent
    valve now folows sane human valve conventions.
    [IntegratedValveControl.ino, RFHybridController.ino]
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2019-11-12 ValveControl: Implement Proper ignition sequence
    Fixed ignition timer to fire reliably with proper timings. Ignition
    lockout happens at the ground controller end, and thus we avoid locking
    out at the engine end in the case of a transmission failure.
    [IntegratedValveControl.ino, RFHybridController.ino]
2019-11-12 ValveControl: Adjust MV-R1 movement offsets
    Dialed in new offset for the new valve. Backlash isn't consistent under
    pressure, but this is the closest we've been able to get full open using
    the encoder on the motor end.
    [IntegratedValveControl.ino, const-ivc.h]
2019-11-20 ValveControl: Add auto run stop after ignition
    Due to burn-through worries, we will shut the run down seven seconds
    after the ignition valve is opened. this will prevent ox flow and the
    control panel operator shall manually actuate it open after flame out is
    confirmed to finish venting.
    [IntegratedValveControl.ino]
2019-11-20 RFHybridController: Make vent button always toggle
    Modified if branching to make the vent button always toggle the vent
    state to allow for miswiring mistakes. This way, if we accidentally
    configured the valve incorrectly, we can just flip the rocker switch to
    rectify it.
    [RFHybridController.ino]
2019-11-20 main.py: write correct header when logging
    We now write the correct header when logging, instead of accidentally
    logging a sensor twice.
    [main.py]
2022-04-08 added wiring info, corrected typos, added all libraries to folder
    [IntersemaBaro.h, Music.cpp, PRO_MICRO.ino]
2022-04-08 changed pin for buzzer
    [GROUND_STATION.ino, PRO_MICRO.ino]
2022-04-10 Fixed compilation issues...
    ...by committing major software sins. :(
    [PRO_MICRO.ino, music_impl.h]
